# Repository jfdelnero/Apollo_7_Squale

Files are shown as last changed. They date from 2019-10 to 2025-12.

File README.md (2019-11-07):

Apollo 7 Squale toolchain and demos  
(c) 2015-2019 Jean-François DEL NERO  
(c) 2015-2019 Association MO5.COM ( [https://mo5.com](https://mo5.com) )
---

gcc6809 based Apollo 7 Squale C toolchain and demos examples

[Squale computer technical page](http://hxc2001.free.fr/Squale/index.html)

[Squale Demo release news letter](http://mag.mo5.com/actu/172742/mo5-com-presente-la-toute-premiere-demo-sur-squale)

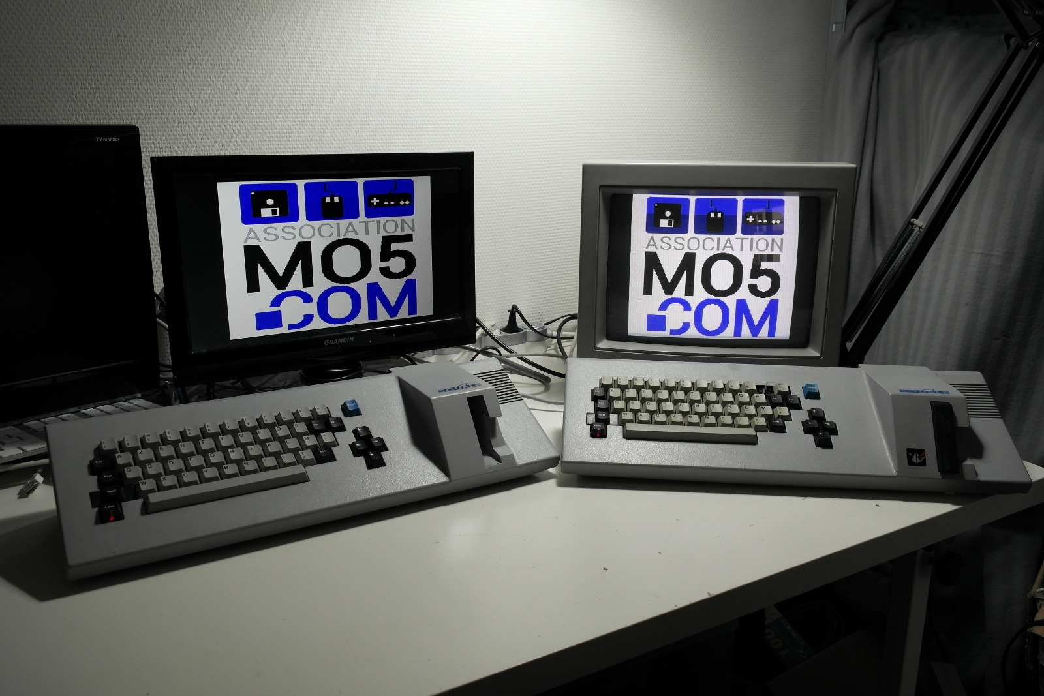
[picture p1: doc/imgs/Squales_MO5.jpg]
Squale_mo5


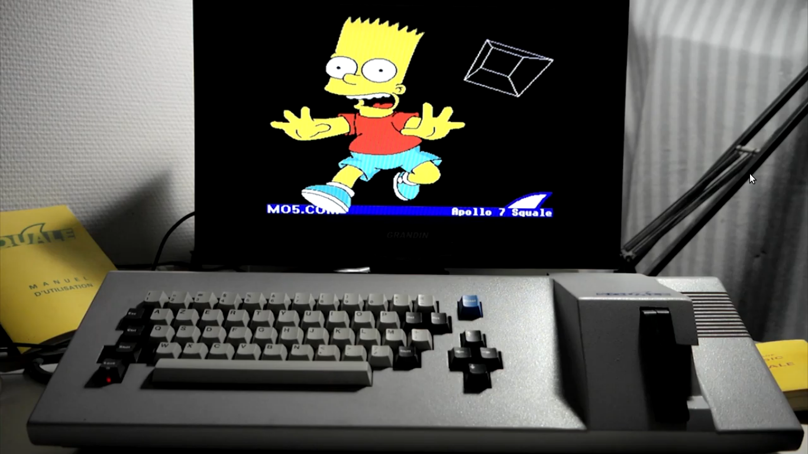
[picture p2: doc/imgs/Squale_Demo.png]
Squale_demo


(https://www.youtube.com/watch?v=cp6OLa2aaII)

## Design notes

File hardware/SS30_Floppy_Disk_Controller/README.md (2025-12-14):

Apollo 7 Squale SS30 Floppy disk drives controller Schematic
---

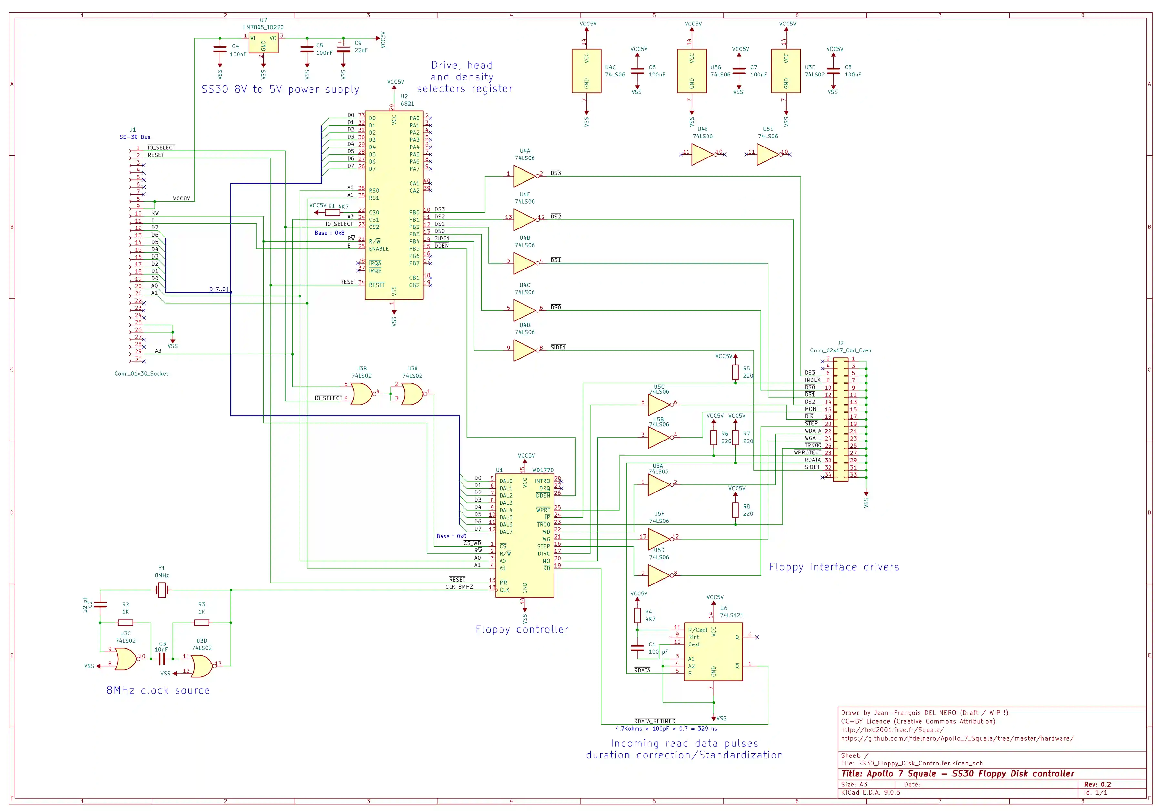
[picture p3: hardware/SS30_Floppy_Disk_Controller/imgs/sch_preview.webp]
Squale_SS30_FloppyController_sch


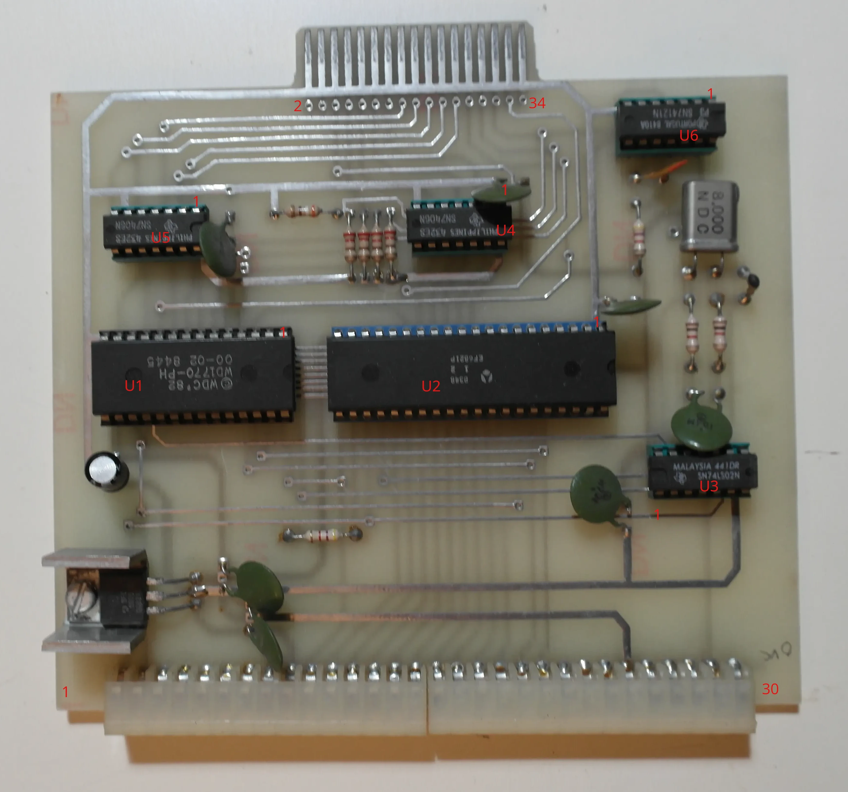
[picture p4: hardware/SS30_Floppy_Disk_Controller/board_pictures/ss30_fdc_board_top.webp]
Squale_SS30_FloppyController_board


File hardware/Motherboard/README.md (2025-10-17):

Apollo 7 Squale Schematic and PCB 
---

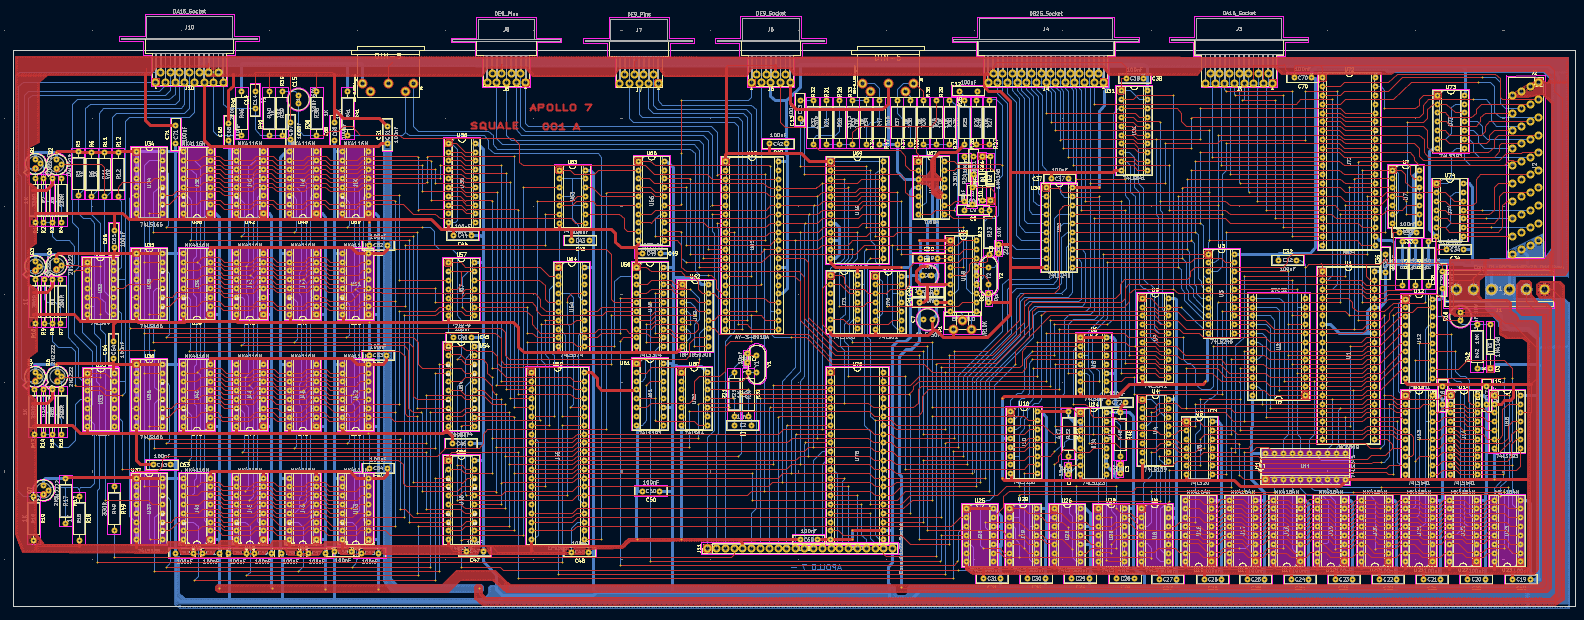
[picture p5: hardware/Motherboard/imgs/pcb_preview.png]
Squale_pcb


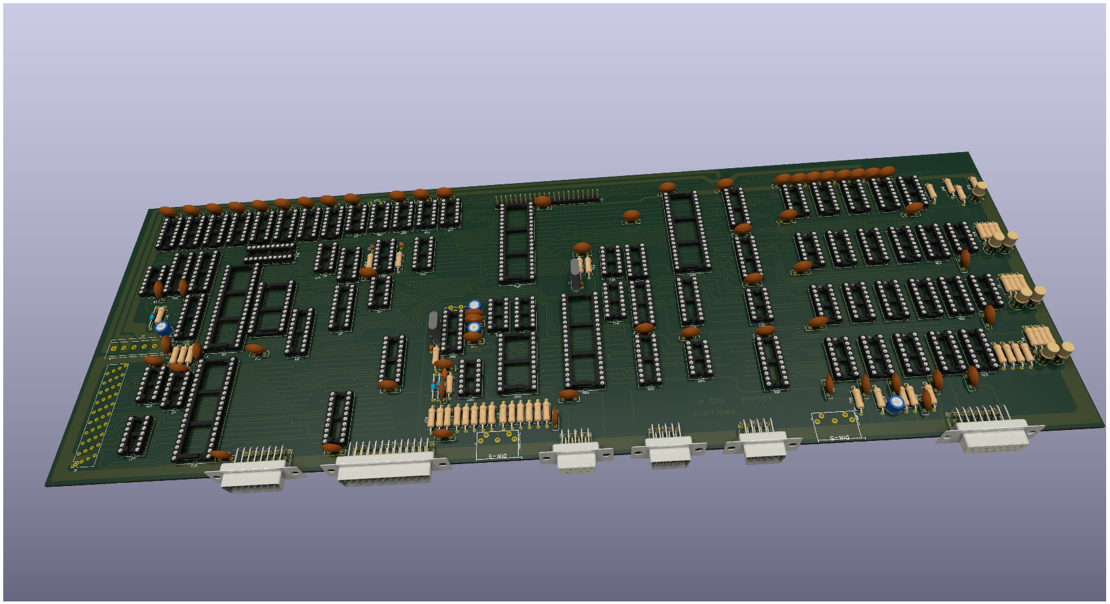
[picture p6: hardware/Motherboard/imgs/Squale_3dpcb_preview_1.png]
Squale_pcb_3d_1


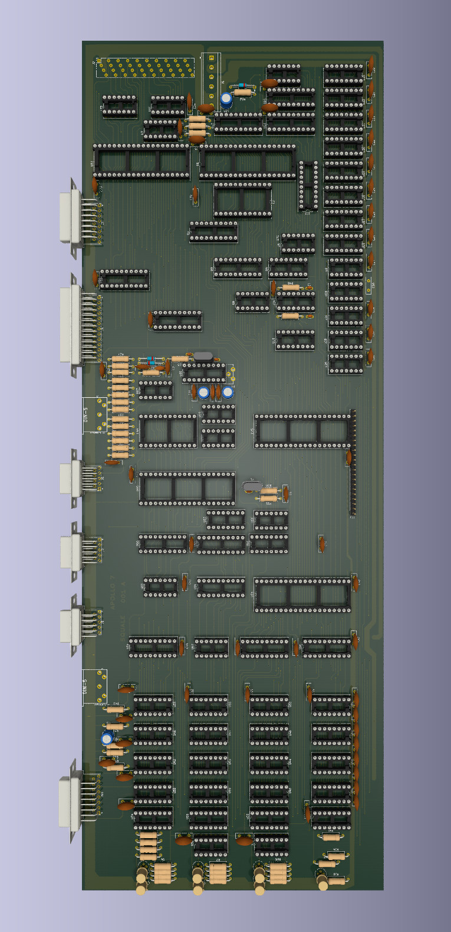
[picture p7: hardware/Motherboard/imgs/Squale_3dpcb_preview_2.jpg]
Squale_pcb_3d_2


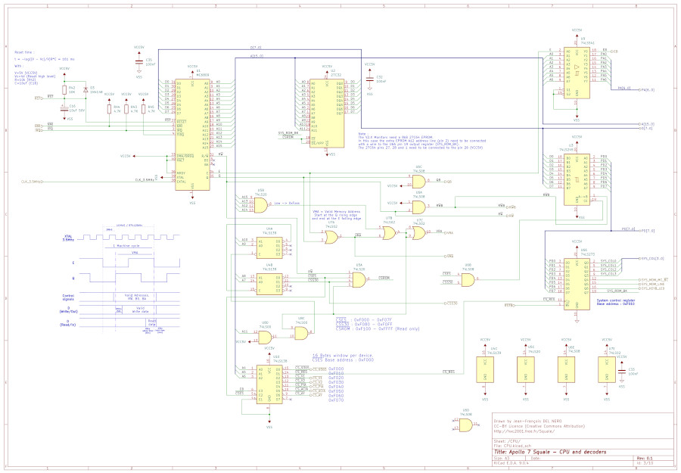
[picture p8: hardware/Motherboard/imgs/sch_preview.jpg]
Squale_sch


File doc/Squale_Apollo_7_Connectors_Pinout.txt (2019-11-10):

----------------------------------------------------------------

PERITELEVISION (Scart)

- Sortie "SQUALE" Cannon DB15 Femelle

- 1 BTV		 Bleu péritel
- 2 VTV		 Vert péritel
- 3 SY+TTL	 Synchro négative TTL
- 4 VTTL	 Vert TTL
- 5 ITTL	 Intensité TTL
- 6 +12V	 12V 100mA
- 7 COMMUT	 Commutation péritel
- 8 SON		 Son Péritel
- 9 SYTV	 Synchro péritel
-10 RTV		 Rouge péritel
-11 BTTL	 Bleu TTL
-12 RTTL	 Rouge TTL
-13 +5V		 +5V 100 mA
-14 MASSE	 MASSE
-15 MASSE	 MASSE

----------------------------------------------------------------

CRAYON LUMINEUX

- Sortie "SQUALE" DIN 5 broches femelle

- 1 +5V		+5V 50mA
- 2 MASSE	MASSE
- 3 INTLP	INTERRUPTEUR CRAYON
- 4
- 5 LP		CRAYON LUMINEUX

----------------------------------------------------------------

MANETTES DE JEUX TYPE "ATARI"

- Sortie "SQUALE" 2 CANNON DB9 MALE

- 1 AV		AVANT
- 2 AR		ARRIERE
- 3 GA		GAUCHE
- 4 DR		DROITE
- 5
- 6 P		POUSSOIR
- 7 +5V		+5V 50mA
- 8 MASSE	MASSE
- 9

----------------------------------------------------------------

MODEM

- Sortie "SQUALE" CANNON DB9 femelle

- 1 CONMODEM 	Connection ligne téléphonique
- 2 RING+		Indicateur de sonnerie
- 3 +5V			+5V 100mA
- 4 DT			Signal MODEM
- 5 Masse SIG	Masse signal
- 6
- 7
- 8	Masse alim 	Masse alim 5V
- 9

----------------------------------------------------------------

MAGNETOPHONE A CASSETTE

- Sortie "SQUALE" DIN 5 broches femelle

- 1 SI			Sortie micro 50mV
- 2 MASSE		Masse
- 3 E1			Entrée
- 4 S2			Sortie aux 1V
- 5 E2			Entrée 2

----------------------------------------------------------------

IMPRIMANTE

- Sortie "SQUALE" Cannon DB15 Male

- 1
- 2 MASSE		MASSE
- 3 MASSE		MASSE
- 4 D8			Donnée 8
- 5 ACK*		Acknowledge
- 6 DSTROBE+	Strobe+
- 7
- 8
- 9 D7			Donnée 7
-10 D6			Donnée 6
-11 D5			Donnée 5
-12 D4			Donnée 4
-13 D3			Donnée 3
-14 D2			Donnée 2
-15 D1			Donnée 1

----------------------------------------------------------------

ROMPACK

- Sortie "SQUALE" 2x20 2,54mm

- 1,2,3,4		MASSE
- 5				D0
- 6				A0
- 7				D1
- 8				A1
- 9				D2
-10				A2
-11				D3
-12				A3
-13				D4
-14				A4
-15				D5
-16				A5
-17				D6
-18				A6
-19				D7
-20				A7
-21
-22				A8
-23
-24				A9
-25
-26				A10
-27
-28				A11
-29
-30				A12
-31
-32				A13
-33
-34				A14
-35
-36				A15
-37,38,39,40	+5V

----------------------------------------------------------------

BUS EXTENSION SS-30

- Sortie "SQUALE" Cannon DB25 Male

- 1				+5V
- 2				NMI*
- 3				A6
- 4				A4
- 5				A2
- 6				A0
- 7				R/W*
- 8				CSS30*
- 9				D1
-10				D3
-11				D5
-12				D7
-13				MASSE
-14				+5V
-15				IRQ*
-16				A5
-17				A3
-18				A1
-19				E
-20				RST*
-21				D0
-22				D2
-23				D4
-24				D6
-25				MASSE

----------------------------------------------------------------

CHASSIS EXTENSION SS-30 Bus

- 1				Board Select
- 2				RST*
- 3
- 4
- 5
- 6
- 7
- 8				+12V ?
- 9				+12V ?
-10				R/W*
-11				E
-12				D7
-13				D6
-14				D5
-15				D4
-16				D3
-17				D2
-18				D1
-19				D0
-20				A1
-21				A0
-22				IRQ* ?
-23				FIRQ* ?
-24
-25				MASSE
-26				MASSE
-27
-28
-29				A3
-30				A2

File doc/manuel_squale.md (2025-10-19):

# MANUEL D'UTILISATION DE L'ORDINATEUR SQUALE

Vous venez de faire l'acquisition de votre nouvel ordinateur.
Avant de le brancher, il est recommandé de lire cette notice. Les lignes qui vont suivre vous permettront d'éviter un certain nombre d'erreurs et d'utiliser au mieux votre "SQUALE".

Dans l'emballage vous devez trouver les éléments suivants :

a/ votre "SQUALE".<br />
b/ un cordon "PERITEL".<br />
c/ une cassette SQ BASIC, SQ FLEX, Jeux<br />
d/ un manuel SBASIC.<br />

Après avoir soigneusement défait de l'emballage tous les éléments, vous installerez votre "SQUALE" sans le brancher pour l'instant.
Cette notice vous aidera à le faire sans risques pour votre matériel.

Il est préférable d'installer le "SQUALE" sur une table dégagée proche de votre téléviseur si vous n'avez pas de moniteur. Vous avez impérativement besoin d'un magnétophone à cassette. Pour vous aider à le choisir, reportez-vous au chapitre suivant.

Il serait également préférable d'avoir à portée de main de quoi prendre des notes.

## LES ÉLÉMENTS DU "SQUALE"

Avant de procéder aux branchements du "SQUALE", il est préférable d'avoir un aperçu des différents éléments qui le composent. Les personnes impatientes peuvent toujours sauter ce chapitre.

**LA PRISE PERITEL**

Cette prise se trouve à l’arrière de tout téléviseur récent. Elle permet de le transformer en terminal d’ordinateur. Cette prise est aussi indispensable au décodeur "CANAL+". Si vous possédez ce décodeur vous devez le débrancher afin de libérer la prise pour le "SQUALE".
Si votre téléviseur n’est pas équipé d’une entrée "PERITEL", vous devez vous procurer un adaptateur UHF. Cet élément a pour objet d’adapter votre "SQUALE" à n’importe quel téléviseur. Il est toutefois à noter que l’usage de l’adaptateur vous fera perdre un peu de définition sur les images graphiques, celles-ci seront légèrement floues. La formule idéale serait d’avoir un moniteur couleur.

Il en existe un, spécialement adapté au "SQUALE". Le mieux serait de vous renseigner auprès de votre revendeur.

**LE MAGNETOPHONE**

Pour pouvoir utiliser les cassettes vous avez besoin d’un magnétophone. Cet appareil n’a pas besoin d’avoir une grande qualité. Il est donc inutile d’acheter une console HI-FI. Vous devez vous assurer que les prises correspondent à votre cordon de raccordement. Sinon, un spécialiste sera en mesure de vous aider. Les prises sont du type "JACK" et équipent la plupart des appareils bon marché.

**LA CASSETTE SBASIC**

La cassette que vous avez reçue avec votre "SQUALE" contient le programme SBASIC. Ce programme est enregistré sous forme codée. Contrairement à une cassette musicale, celle-ci est extrêmement fragile. Il est conseillé de manipuler cette cassette avec précautions.

**LE MANUEL SBASIC**

Le manuel SBASIC est indispensable à ceux qui veulent écrire des programmes. Le SBASIC est très performant et possède de nombreuses instructions que n’ont pas d’autres ordinateurs de même catégorie que le "SQUALE". Dans les pages suivantes vous trouverez des exemples de programmes amusants.

## BRANCHEMENTS DU "SQUALE"

Il y a au minimum deux branchements à faire sur votre "SQUALE",
le premier sera de connecter celui-ci sur votre téléviseur et le second sera de mettre le "SQUALE" sous tension.

**IMPORTANT : AVANT DE COMMENCER ASSUREZ VOUS QUE VOTRE TÉLÉVISEUR EST ÉTEINT.**

Vous allez maintenant procéder aux branchements de votre "SQUALE".

1- Tout d'abord vous installez le cordon "PERITEL" dans la prise qui se trouve placée à l’arrière de votre ordinateur (complètement à droite vu de dos).

2- Ensuite vous branchez l’autre extrémité de ce cordon dans la prise "PERITEL" située à l’arrière de votre téléviseur ou dans votre adaptateur UHF.
Si vous désirez brancher le "SQUALE" sur un MONITEUR couleur, vous devez vous assurer de la compatibilité du cordon de raccordement.

3- Connectez maintenant le cordon qui doit relier le "SQUALE" au magnétophone.
Vous devez faire très attention aux prises. Vous ne devez pas les intervertir.

4- Vous branchez votre "SQUALE" et vous allumez votre téléviseur.

5- Vous pouvez à présent allumer votre ordinateur à l’aide de l’interrupteur situé à l’arrière de votre "SQUALE".
Vous devez voir apparaître, sur votre écran, le message suivant :

*+ SQUALEMON Vx,v.*

Si aucun message n’apparaît à l’écran, appuyez sur la touche bleue marquée "RESET".
Si, au bout de deux secondes environ, vous n’avez toujours rien, éteignez votre ordinateur et demandez conseil à votre revendeur.

## LE MONITEUR DU "SQUALE"

Votre "SQUALE" est maintenant sous le contrôle du PROGRAMME MONITEUR.
Le programme MONITEUR est implanté de manière permanente dans votre "SQUALE". À la suite d’une mise sous tension, ou si l’on presse la touche bleue marquée RESET, le "SQUALE" revient automatiquement sous le contrôle du programme moniteur. Essayez maintenant de presser la touche RESET.
Le moniteur gère l’écran et le clavier. Il affiche le message d’appel, en haut de l’écran, et le signe +. Ce signe indique que le "SQUALE" est prêt à recevoir la première commande. Regardons ensemble ce que nous pouvons faire.

Vous ne pouvez presser que les touches suivantes :

C, D, E, G, M, R, S,
c, d, e, g, m, r, s.

Vous remarquerez qu’il est possible d’utiliser indifféremment les majuscules ou les minuscules.
Voyons ce qui se passe pour chacune de ces touches.

**La touche : C**

C’est l’appel de la cassette. Si, au moment où vous introduisez cette commande, le magnétophone lit une cassette programme, ce programme sera chargé dans le "SQUALE".

**La touche : D**

Si votre "SQUALE" est équipé de lecteurs de disquettes, le fait d’introduire cette commande provoque l’appel du FLEX sur le disque.

**La touche : E**

Cette commande ressemble à la commande "C". La différence est que l’on obtient une exécution immédiate du programme enregistré sur la cassette.

**La touche : G**

Cela veut dire Go (en anglais). La syntaxe est particulière et le simple fait de presser la touche "G" ne suffit pas. Il faut ensuite introduire l’adresse HEXADÉCIMALE du début du programme. Essayez de presser G F100.
Vous venez alors de lancer le programme moniteur comme si vous aviez pressé la touche bleue.

**La touche : M**

Cette commande permet d’examiner une case mémoire. Comme vous pouvez aussi changer le contenu de cette case, il est donc possible d’introduire un programme en langage MACHINE.
Voici comment faire : pressez M 1000, immédiatement le "SQUALE" présente le contenu de la mémoire correspondante. Si vous désirez changer le contenu de cette "case", vous devez introduire maintenant la nouvelle valeur et le "SQUALE" vous présentera automatiquement l’adresse suivante accompagnée de son contenu. Si vous ne désirez pas modifier le contenu de la mémoire vous ...

vous utiliser les touches fléchées, vers le haut pour voir la mémoire précédente et vers le bas pour la suivante. Cela n’est pas très compliqué mais demande un peu d’habitude.

**La touche : R**

Si vous pressez cette touche, vous demandez au "SQUALE" de lancer la ROMPACK. Le "SQUALE" vient la lire et exécute le programme qu’elle contient. Si vous voulez savoir ce qu’est une ROMPACK vous devez vous reporter au chapitre Mémoire du "SQUALE".

**La touche : S**

Cette dernière commande permet d’enregistrer sur cassette le contenu d’une zone de la mémoire. Celle-ci doit contenir un programme exécutable.
La syntaxe est la suivante : S xxxx yyyy zzzz.
xxxx est l’adresse du début de l’espace à sauver.
yyyy est la fin de cet espace.
zzzz représente l’adresse d’exécution de ce programme.

Les non initiés auront du mal à utiliser cette instruction.

## LA MÉMOIRE DU "SQUALE"

Pour faire fonctionner un ordinateur il faut pouvoir lui donner des instructions. Celles-ci devront se trouver dans une mémoire. Nous avons vu que le programme moniteur était RESIDENT. C’est à dire qu’il existe quelque part dans l’appareil une mémoire qui le contient. Essayez par exemple de modifier à l’aide de la commande moniteur "M" le contenu de l’adresse F100. Vous verrez que cela est impossible. Cette mémoire que rien ne peut altérer s’appelle une mémoire MORTE. Cette mémoire occupe 4096 adresses.
Par opposition il existe dans le "SQUALE" une mémoire VIVE. On appelle comme cela toutes mémoires que l’on peut modifier. Comme il est possible de modifier cette mémoire c’est par conséquent dans celle-ci que nous chargerons nos programmes. Il existe dans le "SQUALE" 61440 Octets de mémoire vive utilisable.
Pour charger un programme dans le "SQUALE" nous n’avons que l’embarras du choix. La méthode que nous connaissons à présent est celle qui consiste à utiliser le clavier pour modifier le contenu de la mémoire vive. Cette solution est de loin la plus fastidieuse et la plus sujette aux erreurs.
La meilleure solution pour introduire un programme dans un ordinateur est d’utiliser une MÉMOIRE DE MASSE. Une mémoire de masse est, en général, extérieure à l’ordinateur et peut contenir un très grand nombre d’instructions exécutables. C’est en général un support magnétique, une cassette ou une disquette. Le "SQUALE" est en mesure d’utiliser ces deux dernières. De plus vous trouverez un grand nombre de programmes disponibles sous forme de ROMPACK.

La ROMPACK du "SQUALE" n’est autre que l’association de plusieurs mémoires mortes. L’ensemble constitue une sorte de mémoire de masse. La seule différence est qu’il est impossible d’écrire sur une ROMPACK. Par contre une ROMPACK est un support de programmes bien moins fragile qu’une bande magnétique.

## LE GRAPHISME DU "SQUALE"

Le "SQUALE" est un des ordinateurs de sa catégorie qui possède les plus grandes qualités graphiques. Il est en effet équipé d’un coprocesseur spécialisé et d’une mémoire séparée. Le résultat est que le "SQUALE" possède une résolution graphique de 256 points par lignes et 256 lignes affichées. Chacun de ces points élémentaires (pixels) peut être représenté en 16 couleurs différentes.

Afin de sauvegarder son image haute résolution, il a été nécessaire d’ajouter au "SQUALE" plus d’un million de bits de mémoire. Cette mémoire est appelée mémoire VIDEO.

En plus de ses qualités picturales, le "SQUALE" est capable de dessiner à une très grande vitesse. En effet le coprocesseur graphique est capable d’écrire 1500000 pixels par seconde. Il est naturel de penser que certains programmes vont exploiter ces possibilités. Notamment les jeux.

## LE CLAVIER DU "SQUALE"

Le clavier est constitué physiquement de 55 touches. C’est un clavier AZERTY, c’est à dire Français.
Les touches sont divisées en trois groupes de couleurs :
    • 11 touches noires de fonctions dont quatre, séparées des autres, comportent des flèches.
    • 43 touches grises alphanumériques.
    • Et une touche bleue marquée "RESET".
Nous allons étudier ces touches à l’aide de quelques exemples.

**La touche RESET :**

Nous observons qu’elle est séparée des autres physiquement et que sa couleur est particulière. Sa fonction est de remettre le "SQUALE" à zéro. Si vous pressez maintenant cette touche le "SQUALE" revient à sa position de départ et affiche obligatoirement le message du programme moniteur. Si une ROMPACK est en place, celle-ci sera lue par le "SQUALE". Il est évident qu’une fausse manœuvre de cette touche engendre la perte de votre programme.

**Les touches noires fléchées :**

Elles servent principalement à déplacer le curseur sur l’écran. C’est un excellent outil pour corriger les fautes sur une ligne de programme. Elles peuvent aussi être utilisées dans certains jeux. Nous reviendrons sur l’utilisation de ces touches.

**Les touches noires de contrôle :**

Tout d’abord nous allons voir la principale : la touche "RET".
Placée sur la deuxième rangée, en partant du haut, à droite, la touche "RET" est certainement la plus importante. C’est le RETOUR. Cela veut dire à votre "SQUALE" que ce que vous avez écrit est valable et doit être considéré comme une instruction. Si vous êtes sous basic et que le message "PRET" est affiché, vous pouvez essayer l’exemple suivant :

Écrivez : PRINT "TOTO".

CLAVIER SQUALE

Control Ø   (zéro)   = insertion de caractère

Control :   (2pts)   = effacement de ligne par la droite

Control -   (moins)  = tabulation

Control R             = répétition de la dernière instruction
                        (ex = RUN)

DEL                   = effacement de ligne par la gauche

## MODE D'EMPLOI CASSETTE

1. Relier le magnétophone au SQUALE
2. Insérer la cassette côté SQBasic SQFLEX. (cassette en début de bande)
3. Mettre le SQUALE sous tension.
4. Appuyer sur la touche E.
5. Démarrer le magnétophone.
6. Après 15 secondes le SQUALE affiche un message : la lecture de la cassette s'effectue.
7. Après 5 minutes le programme SBASIC est chargé.
8. Le SQUALE affiche PRET<br />
8 BIS. Utilisation du jeu POKER
9. Retourner la cassette
10. Amener la cassette en début de bande.
11. Afficher à l'aide du clavier C LOAD.
12. Appuyer sur la touche RET.
13. SQUALE affiche K7 Prête ?
14. Appuyer sur la touche RET.
15. Démarrer le magnétophone.
16. Après 15 secondes, SQUALE affiche P
17. Après 4 minutes le jeu POKER est chargé, SQUALE affiche PRET.
18. Frapper RUN
19. Vous pouvez maintenant jouer.

**Note additionnelle :**

Utilisez les touches du déplacement du curseur pour placer le dernier (gauche, droite) sous la carte choisie.
La touche de déplacement vers le haut servant à valider ou éliminer la carte
(un liseré de couleur apparaît autour de la carte pour l'annuler).

## CONNECTEURS SORTIES "SQUALE"

**PÉRITÉLÉVISION**

Sortie "SQUALE" : Cannon DB15 Femelle

| Pin | Signal | Description |
|-----|---|---|
| 1 | BTV | Bleu péritel |
| 2 | VTV | Vert péritel |
| 3 | SY+TTL | Synchro négative TTL |
| 4 | VTTL | Vert TTL |
| 5 | ITTL | Intensité TTL |
| 6 | +12V | +12V 100 mA |
| 7 | COMMUT | Commutation péritel  |
| 8 | SON | Son Péritel |
| 9 | SYTV | Synchro péritel |
| 10  | RTV | Rouge péritel |
| 11  | BTTL | Bleu TTL |
| 12  | RTTL | Rouge TTL |
| 13  | +5V | +5V 100 mA |
| 14  | MASSE  | MASSE |
| 15  | MASSE  | MASSE |

**CRAYON LUMINEUX**

Sortie "SQUALE" : DIN 5 broches femelle

| Pin | Signal | Description |
|-----|---|---|
| 1 | +5V | +5V 50 mA |
| 2 | MASSE  | MASSE |
| 3 | INTLP  | INTERRUPTEUR CRAYON |
| 4 | | |
| 5 | LP | CRAYON LUMINEUX |

**MANETTES DE JEUX TYPE "ATARI"**

Sortie "SQUALE" : 2 CANNON DB9 MALE

| Pin | Signal | Description |
|-----|---|---|
| 1 | AV | AVANT |
| 2 | AR | ARRIÈRE |
| 3 | GA | GAUCHE |
| 4 | DR | DROITE |
| 5 | | |
| 6 | P | POUSSOIR |
| 7 | +5V | +5V 50 mA |
| 8 | MASSE  | MASSE |
| 9 | | |

**MODEM**

Sortie "SQUALE" : CANNON DB9 femelle

| Pin | Signal | Description |
|-----|---|---|
| 1 | CONMODEM | Connexion ligne téléphonique |
| 2 | RING* | Indicateur de sonnerie |
| 3 | +5V | +5V 100 mA |
| 4 | DT | Signal MODEM |
| 5 | Masse SIG  | Masse signal |
| 6 | | |
| 7 | | |
| 8 | Masse alim | Masse alim 5V |
| 9 | | |

**MAGNÉTOPHONE À CASSETTE**

Sortie "SQUALE" : DIN 5 broches femelle

| Pin | Signal | Description |
|-----|---|---|
| 1 | S1 | Sortie micro 50mV |
| 2 | MASSE  | Masse |
| 3 | E1 | Entrée |
| 4 | S2 | Sortie aux 1V |
| 5 | E2 | Entrée 2 |

**IMPRIMANTE**

Sortie "SQUALE" : Cannon DB15 Male

| Pin | Signal | Description |
|-----|---|---|
| 1 | | (non précisé) |
| 2 | MASSE | MASSE |
| 3 | MASSE | MASSE |
| 4 | D8 | Donnée 8 |
| 5 | ACK* | Acknowledge |
| 6 | DSTROBE+ | Strobe + |
| 7 | | (non précisé) |
| 8 | | (non précisé) |
| 9 | D7 | Donnée 7 |
| 10  | D6 | |
| 11  | D5 | |
| 12  | D4 | |
| 13  | D3 | |
| 14  | D2 | |
| 15  | D1 | |

**ROMPACK**

Sortie "SQUALE" : Connecteur 2×20 à pas de 2,54 mm

| Pin(s) | Signal |
|---|---|
| 1,2,3,4 | MASSE  |
| 5 | D0 |
| 6 | A0 |
| 7 | D1 |
| 8 | A1 |
| 9 | D2 |
| 10 | A2 |
| 11 | D3 |
| 12 | A3 |
| 13 | D4 |
| 14 | A4 |
| 15 | D5 |
| 16 | A5 |
| 17 | D6 |
| 18 | A6 |
| 19 | D7 |
| 20 | A7 |
| 21 | |
| 22 | A8 |
| 23 | |
| 24 | A9 |
| 25 | |
| 26 | A10 |
| 27 | |
| 28 | A11 |
| 29 | |
| 30 | A12 |
| 31 | |
| 32 | A13 |
| 33 | |
| 34 | A14 |
| 35 | |
| 36 | A15 |
| 37,38,39,40 | +5V |

**BUS EXTENSION SS30**

Sortie "SQUALE" : DB25 Male

| Pin | Signal | Remarques |
|-----|---|---|
| 1 | +5V | |
| 2 | NMI* | Non-maskable interrupt |
| 3 | A6 | |
| 4 | A4 | |
| 5 | A2 | |
| 6 | A0 | |
| 7 | R/W* | Lecture/Écriture |
| 8 | CSS30* | Chip Select SS30 |
| 9 | D1 | |
| 10  | D3 | |
| 11  | D5 | |
| 12  | D7 | |
| 13  | MASSE  | |
| 14  | +5V | |
| 15  | IRQ* | Requête d'interruption |
| 16  | A5 | |
| 17  | A3 | |
| 18  | A1 | |
| 19  | E | Horloge CPU ? |
| 20  | RST* | Reset |
| 21  | D0 | |
| 22  | D2 | |
| 23  | D4 | |
| 24  | D6 | |
| 25  | MASSE  | |

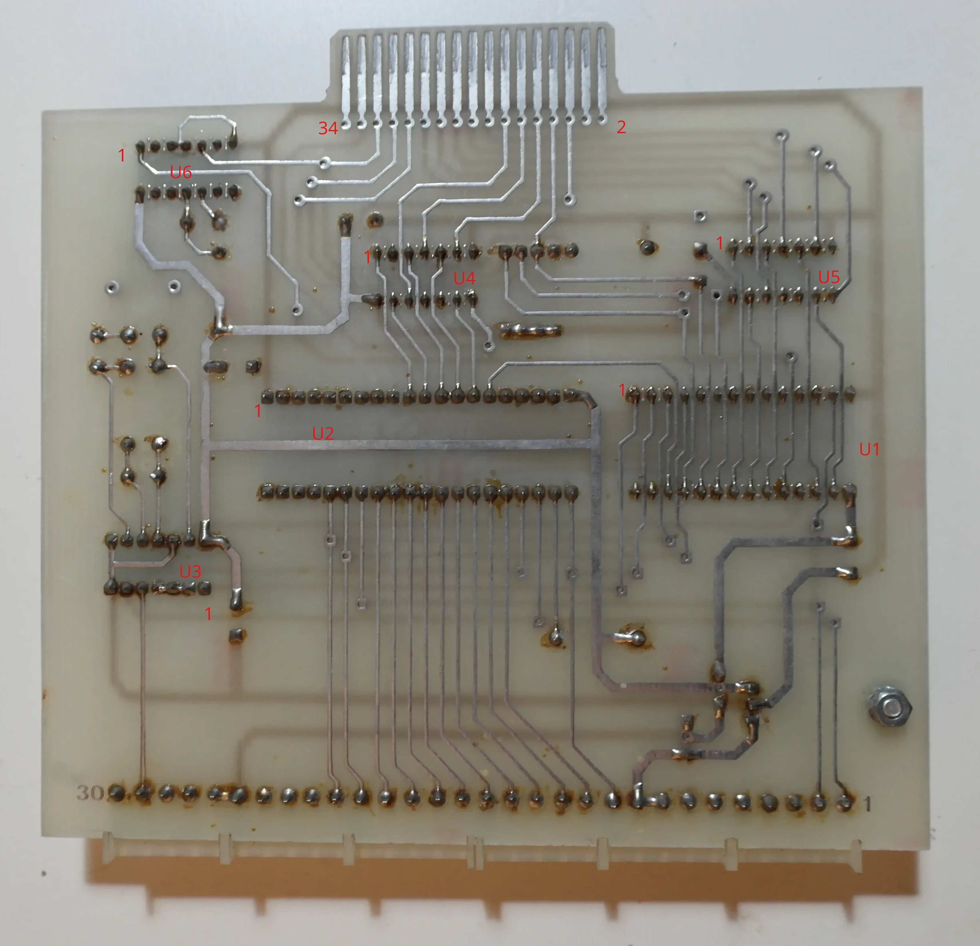
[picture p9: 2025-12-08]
hardware/SS30_Floppy_Disk_Controller/board_pictures/ss30_fdc_board_bottom.webp

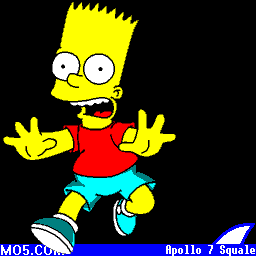
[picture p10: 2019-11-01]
examples/Squale_Technical_Demo/images/bart_footpage.bmp

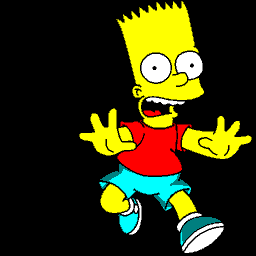
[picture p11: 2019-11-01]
examples/Squale_Technical_Demo/images/bart.bmp

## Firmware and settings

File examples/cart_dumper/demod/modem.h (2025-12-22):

/*
//
// Copyright (C) 2022-2023 Jean-François DEL NERO
//
// This file is part of vdt2bmp.
//
// vdt2bmp may be used and distributed without restriction provided
// that this copyright statement is not removed from the file and that any
// derivative work contains the original copyright notice and the associated
// disclaimer.
//
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
*/

#define DEFAULT_NUMBER_OF_CHANNELS 1
#define DEFAULT_SAMPLERATE 44100

#if defined(M_PI)
#define PI M_PI
#else
#define PI 3.1415926535897932384626433832795
#endif

#define DEFAULT_SOUND_BUFFER_SIZE 2048

typedef struct mean_ctx_
{
	float mean_h[512];
	int  mean_wr_idx;
	int  mean_max_idx;

	float mean;
}mean_ctx;

typedef struct modem_demodulator_ctx_
{
	unsigned int freqs[2];
	float mod_step[2];
	float phase[2];

	unsigned int sample_rate;
	float old_integrator_res[4];
	float power[4];
	float add[2];

	mean_ctx mean[4];

	int bit_time;

	int uart_rx_idx;

	int carrier_detect;

	unsigned int wave_in_pages_cnt;

}modem_demodulator_ctx;

typedef struct serial_rx_
{
	int serial_rx_delay;
	int serial_rx_prev_state;
	int serial_rx_state;
	unsigned short serial_rx_shiftreg;
	int serial_rx_parbitcnt;
	int serial_rx_cnt;

	float bit_time;

	int fifo_idx;

	unsigned int last_rx_tick;
}serial_rx_ctx;

typedef struct modem_ctx_
{
	int serial_pre_idle;
	int serial_nbstart;
	int serial_nbits;
	int serial_nbstop;
	int serial_parity;
	int serial_post_idle;
	int serial_msb_first;

	unsigned int last_tx_tick;

	unsigned int freqs[3];
	float mod_step[3];
	float phase;

	int last_bitstate;

	int sample_rate;
	int Amplitude;

	int baud_rate;

	float bit_time;
	int  tx_bittime_cnt;

	int tx_buffer[64];
	int tx_buffer_size;
	int tx_buffer_offset;

	short * wave_buf;
	int wave_size;

	unsigned int samples_generated_cnt;

	modem_demodulator_ctx demodulators[4];

	serial_rx_ctx serial_rx[2];
	serial_fifo rx_fifo[2];

	serial_fifo tx_fifo;

	unsigned int wave_out_pages_cnt;

}modem_ctx;

void mdm_init(modem_ctx *mdm);

void mdm_cfg_demod(modem_ctx *mdm, modem_demodulator_ctx * demod, int baud_rate, int sample_rate, int zero_freq, int one_freq, int rxuart_idx);

int  mdm_prepare_next_word(modem_ctx * mdm, int * tx_buffer,unsigned char byte);
int  mdm_genWave(modem_ctx *mdm, short * buf, int size);
void mdm_demodulate(modem_ctx *mdm, modem_demodulator_ctx *mdm_dmt, short * wavebuf,int samplescnt);

int  mdm_is_carrier_present(modem_ctx *mdm, modem_demodulator_ctx *mdm_dmt);

int  write_wave_file(char* filename,short * wavebuf,int size,int samplerate);

float freq2step(unsigned int sample_rate, int freq );

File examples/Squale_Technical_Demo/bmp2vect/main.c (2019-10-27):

/*
//
// Copyright (C) 2017-2019 Jean-François DEL NERO / HxC2001
//
// This file is part of the Squale-bmp2vect software
//
// Squale-bmp2vect may be used and distributed without restriction provided
// that this copyright statement is not removed from the file and that any
// derivative work contains the original copyright notice and the associated
// disclaimer.
//
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
*/

#include <stdio.h>
#include <stdlib.h>
#include <string.h>

#include <stdint.h>

#include "bmp_file.h"

// default settings

#define MAX_PARAM_ARG_SIZE 512

void generate_source_files(char * outfile, unsigned char * buf, int size)
{
	int i;
	FILE * f;
	char filename[MAX_PARAM_ARG_SIZE];

	f = 0;

	if(strlen(outfile))
	{
		// Create header file
		strcpy(filename,outfile);
		strcat(filename,".h");
		f = fopen(filename , "w");
		if(f)
		{
			fprintf(f,"/////////////////////////////////\n");
			fprintf(f,"//  Vector generated BMP data  //\n");
			fprintf(f,"/////////////////////////////////\n");
			fprintf(f,"\n");
			fprintf(f,"extern const unsigned char bmp_data_%s[];\n",outfile);
			fclose(f);
		}

		strcpy(filename,outfile);
		strcat(filename,".c");

		f = fopen(filename , "w");
	}

	if(!f)
		f = stdout;

	fprintf(f,"/////////////////////////////////\n");
	fprintf(f,"//  Vector generated BMP data  //\n");
	fprintf(f,"/////////////////////////////////\n");
	fprintf(f,"\n");

	fprintf(f,"#include \x22%s.h\x22\n",outfile);

	fprintf(f,"\n");

	fprintf(f,"const unsigned char bmp_data_%s[] =\n",outfile);

	for(i=0;i<size;i++)
	{
		if(!(i&0xF))
		{
			if(i)
			{
				fprintf(f,"\n\t");
			}
			else
			{
				fprintf(f,"\x7B\n\t");
			}
		}

		fprintf(f,"0x%.2X",buf[i]);

		if( i < size - 1 )
		{
			fprintf(f,",");
		}
		else
		{
			fprintf(f,"\n\x7D\x3B\n");
		}
	}

	if( f != stdout )
	{
		fclose(f);
	}
}

unsigned long getpixstate(bitmap_data * bdata, int xpos, int ypos)
{
	if( (xpos < bdata->xsize) && (ypos < bdata->ysize) )
	{
		return bdata->data[( bdata->xsize * ypos ) + xpos];
	}
	else
	{
		printf("getpixstate : outside bmp ! : %d x %d\n", xpos, ypos );
	}
	return 0;
}

int isOption(int argc, char* argv[],char * paramtosearch,char * argtoparam)
{
	int param=1;
	int i,j;

	char option[512];

	memset(option,0,sizeof(option));
	while(param<=argc)
	{
		if(argv[param])
		{
			if(argv[param][0]=='-')
			{
				memset(option,0,sizeof(option));

				j=0;
				i=1;
				while( argv[param][i] && argv[param][i]!=':')
				{
					option[j]=argv[param][i];
					i++;
					j++;
				}

				if( !strcmp(option,paramtosearch) )
				{
					if(argtoparam)
					{
						if(argv[param][i]==':')
						{
							i++;
							j=0;
							while( argv[param][i] && j < ( MAX_PARAM_ARG_SIZE - 1 ) )
							{
								argtoparam[j]=argv[param][i];
								i++;
								j++;
							}
							argtoparam[j]=0;
							return 1;
						}
						else
						{
							return -1;
						}
					}
					else
					{
						return 1;
					}
				}
			}
		}
		param++;
	}

	return 0;
}

void printhelp(char* argv[])
{
	printf("Options:\n");
	printf("  -help \t\t\t\t: This help\n");
	printf("  -file:[filename]\t\t\t: Input bmp file\n");
	printf("  -fontname:[name]\t\t\t: Output font name\n");
	printf("\n");
}

unsigned long col2index[16]=
{
	0xFFFFFF,
	0x00FFFF,
	0xFF00FF,
	0x0000FF,
	0xFFFF00,
	0x00FF00,
	0xFF0000,
	0x000000,
	0x7F7F7F,
	0x007F7F,
	0x7F007F,
	0x00007F,
	0x7F7F00,
	0x007F00,
	0x7F0000,
	0x000000
};

unsigned char getcolorindex(unsigned long rgb)
{
	int i;

	for(i=0;i<16;i++)
	{
		if(col2index[i] == rgb )
		{
			return i;
		}
	}

	return 0;
}

unsigned char * pack_bmp( bitmap_data * bdata, int * size )
{
	int x,y,cntentries;
	unsigned char lastcolor,newcolor;
	unsigned int rlecnt;
	unsigned char * outbuffer;
	unsigned char * start_ptr;
	unsigned char * cnt_ptr;

	outbuffer = malloc( bdata->xsize * bdata->ysize );

	start_ptr = outbuffer;

	if(bdata->ysize > 255)
		*outbuffer++ = 255;
	else
		*outbuffer++ = bdata->ysize;

	for(y = 0; y < bdata->ysize ;y++)
	{
		rlecnt = 0;
		lastcolor = getcolorindex(getpixstate( bdata, 0, y));

		cnt_ptr = outbuffer;

		*outbuffer++ = 0x00;
		cntentries = 0;

		for(x = 0; x < bdata->xsize ;x++)
		{
			newcolor = getcolorindex(getpixstate( bdata, x, y));

			if( newcolor == lastcolor )
			{
				rlecnt++;
				if( rlecnt > 255 )
				{
					*outbuffer++ = 	( (0x00 << 4) | (lastcolor & 0xF) );
					*outbuffer++ = 255;
					rlecnt -= 255;
					cntentries++;
				}
			}
			else
			{
				if(rlecnt <= 15)
				{
					*outbuffer++ = 	( (rlecnt << 4) | (lastcolor & 0xF) );
					cntentries++;
				}
				else
				{
					*outbuffer++ = 	( (0x00 << 4) | (lastcolor & 0xF) );
					*outbuffer++ = rlecnt;
					cntentries++;
				}

				rlecnt = 1;
			}

			lastcolor = newcolor;
		}

		if(rlecnt)
		{
			if(rlecnt <= 15)
			{
				*outbuffer++ = 	( (rlecnt << 4) | (lastcolor & 0xF) );
				cntentries++;
			}
			else
			{
				*outbuffer++ = 	( (0x00 << 4) | (lastcolor & 0xF) );
				*outbuffer++ = rlecnt;
				cntentries++;
			}
		}

		*cnt_ptr = cntentries;
	}

	*size = outbuffer - start_ptr;

	return start_ptr;
}

int main(int argc, char *argv[])
{
	int bufsize;
	bitmap_data bdata;
	unsigned char * packedimage;
	char filename[MAX_PARAM_ARG_SIZE];
	char fontname[MAX_PARAM_ARG_SIZE];

	printf("Squale bmp2vect v0.1\n");
	printf("(c) Jean-François DEL NERO / HxC2001 2019\n\n");

	// help option...
	if(isOption(argc,argv,"help",0)>0)
	{
		printhelp(argv);
	}

	memset(filename,0,sizeof(filename));
	if(isOption(argc,argv,"file",(char*)&filename)>0)
	{
		printf("Input file : %s\n",filename);
	}

	memset(fontname,0,sizeof(fontname));
	if(isOption(argc,argv,"imagename",(char*)&fontname)>0)
	{
		printf("Image name : %s\n",fontname);
	}

	if(strlen(filename))
	{
		if(!bmp_load(filename,&bdata))
		{
			printf("\nBmp Loaded... Xsize: %d, Ysize: %d\n",bdata.xsize,bdata.ysize);

			packedimage = pack_bmp( &bdata, &bufsize );

			// Get the sprite size.
			generate_source_files(fontname, (unsigned char*)packedimage, bufsize);

			free(packedimage);
		}
	}
	else
	{
		printhelp(argv);
	}
}

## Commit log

2019-10-19 interrupt driven music player.
2019-10-27 Fix output image size.
    [main.c]
2019-11-02 Switch from 16 to 32 bytes YM page size : The final demo fit into the 32KB ROM with this new setting.
2019-11-07 carriage return.
2019-11-10 Ports/Connectors pinout.
2025-08-14 Squale schematic : Initial commit. Work in progress ...
    [CPU.kicad_sch, DRAM.kicad_sch, Keyboard.kicad_sch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]
2025-08-21 PCBAnnot motherboard project.
2025-08-31 WIP -rom pack
    [CPU.kicad_sch, Clocks.kicad_sch, DRAM.kicad_sch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]
2025-09-01 S30 bus + annotations fixes.
    [CPU.kicad_sch, Clocks.kicad_sch, Keyboard.kicad_sch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]
2025-09-02 wip : modem
    [Keyboard.kicad_sch, Squale.kicad_sch, Video_RAM.kicad_sch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]
2025-09-08 wip: tape / modem interface.
    [Squale.kicad_sch, tape_modem.kicad_sch]
2025-09-09 LTspice modem filter simulation.
2025-09-09 R32 and R36 values fixed. Gain fixed.
    [tape_modem.kicad_sch]
2025-09-10 signals levels.
    [tape_modem.kicad_sch]
2025-09-16 WIP : passives parts, cosmetic stuffs.
    [CPU.kicad_sch, Clocks.kicad_sch, DRAM.kicad_sch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]
2025-09-16 duplicated U8E
    [CPU.kicad_sch]
2025-09-27 first import.
    [Squale.kicad_pcb]
2025-09-27 first ICs approximate placement
    [Squale.kicad_pcb]
2025-09-28 Full & scripted placement, based on the PCBAnnot data.
    [Squale.kicad_pcb]
2025-09-28 Fix DRAM address bus connection.
    [DRAM.kicad_sch, Squale.kicad_pcb]
2025-10-02 Fix DRAM address bits ordering.
    [DRAM.kicad_sch]
2025-10-02 missing addresses?
    [DRAM.kicad_sch]
2025-10-04 Fix buffer direction
    [CPU.kicad_sch]
2025-10-04 fix dram address bit order.
    [Video_RAM.kicad_sch]
2025-10-04 Fix vr connections.
    [tape_modem.kicad_sch]
2025-10-04 Some connections fixed.
    [Squale.kicad_sch]
2025-10-04 WIP : Motherboard layout.
    [Squale.kicad_pcb]
2025-10-05 power traces wip..
    [Squale.kicad_pcb]
2025-10-05 eprom vcc fix.
    [CPU.kicad_sch]
2025-10-06 fix footprint.
    [tape_modem.kicad_sch]
2025-10-06 fix footprint
    [ROM_pack.kicad_sch]
2025-10-06 some footprints fixes and minor changes.
    [Squale.kicad_pcb]
2025-10-06 Connectors footprint.
    [CPU.kicad_sch, ROM_pack.kicad_sch, Squale.kicad_sch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]
2025-10-06 Fix footprints and many drc errors.
    [Squale.kicad_pcb]
2025-10-06 more fixes !
    [CPU.kicad_sch, DRAM.kicad_sch, Squale.kicad_pcb]
2025-10-07 connection fix + power line width.
    [Squale.kicad_pcb, Squale.kicad_sch]
2025-10-08 more minor fixes.
    [Squale.kicad_pcb]
2025-10-10 add some descriptions / comments.
    [CPU.kicad_sch, DRAM.kicad_sch, Keyboard.kicad_sch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]
2025-10-11 connection fix
    [Video_RAM.kicad_sch]
2025-10-11 github url + version
    [CPU.kicad_sch, Clocks.kicad_sch, DRAM.kicad_sch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]
2025-12-08 SS30 Floppy Disk Controller schematic : initial commit
    [SS30_Floppy_Disk_Controller.kicad_pcb, SS30_Floppy_Disk_Controller.kicad_sch]
2025-12-08 WIP : schematic
    [SS30_Floppy_Disk_Controller.kicad_sch]
2025-12-08 board pictures
2025-12-08 WIP : annotation.
    [SS30_Floppy_Disk_Controller.kicad_sch]
2025-12-14 fix some missing values.
    [SS30_Floppy_Disk_Controller.kicad_sch]
2025-12-14 comment/notes added.
    [SS30_Floppy_Disk_Controller.kicad_sch]
2025-12-14 port -> register
    [SS30_Floppy_Disk_Controller.kicad_sch]

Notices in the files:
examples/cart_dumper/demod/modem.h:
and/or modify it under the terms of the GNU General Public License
